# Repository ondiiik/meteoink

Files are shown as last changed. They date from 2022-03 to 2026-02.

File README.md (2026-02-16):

# Meteoink

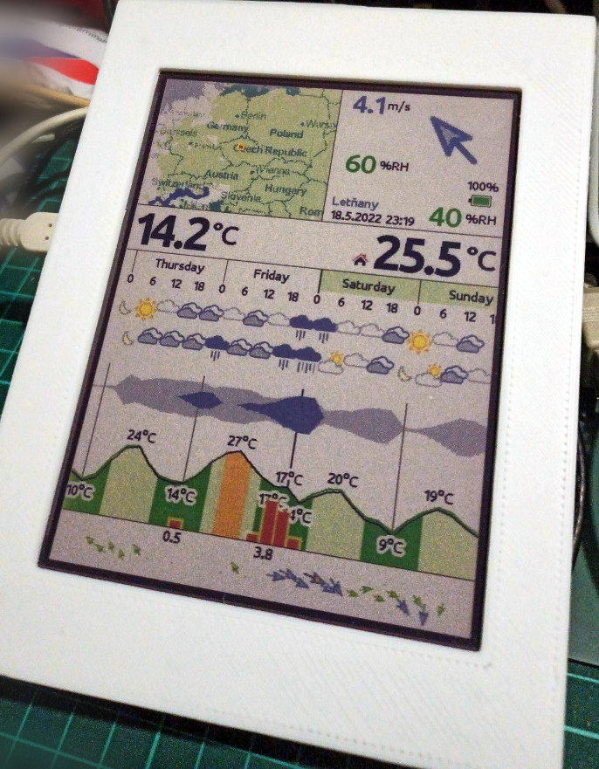
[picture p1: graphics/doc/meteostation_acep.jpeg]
EPD 5.65 ACEP inch meteostation


## What Meteoink is

Meteoink is home meteostation based on several variants of E-Ink displays such as
[5.65inch 7-color (F) E-Ink display](https://www.waveshare.com/wiki/5.65inch_e-Paper_Module_(F)_Manual) (variant `acep`) or
[4.2 inch dual color E-Ink display](https://www.waveshare.com/4.2inch-e-paper-module-c.htm) (variant `bwy`). In past
there has been support also for [T5-4.7 Inch E-paper](https://www.lilygo.cc/products/t5-4-7-inch-e-paper) (variant `epd47`)
but this has been dropped as there is no support for later variant of Micropython (unfortunately several last versions
does not support it due to Micropython version upgrade).

Platform running this meteostation is [Micropython 1.27.0](https://micropython.org/) running on
[TTGO-T8-ESP32](https://github.com/LilyGO/TTGO-T8-ESP32/tree/master) compatible board.

Meteostation is connected to your home WiFi and uses data from [OpenWeatherMap](https://openweathermap.org/).
It also may use [DHT22](https://github.com/semestrinis/Arduino/wiki/DHT22-temperature-humidity-sensor)
sensor for measuring indoor temperature and humidity, however advanced users may use some other MQTT sensor for
this purpose. Whole system is powered from one [Li-On battery](https://en.wikipedia.org/wiki/List_of_battery_sizes#Lithium-ion_batteries_(rechargeable)) charged through the USB on ESP board. Meteostation is usually operating in between 2 to 6 mounts
when refresh time is set to 15 minutes and there is good WiFi signal and internet connection with battery stronger then 3000 mAh.
This time may reduce when e.g. radar data or `acep` variant of display with longer refresh are used.

## Wiring

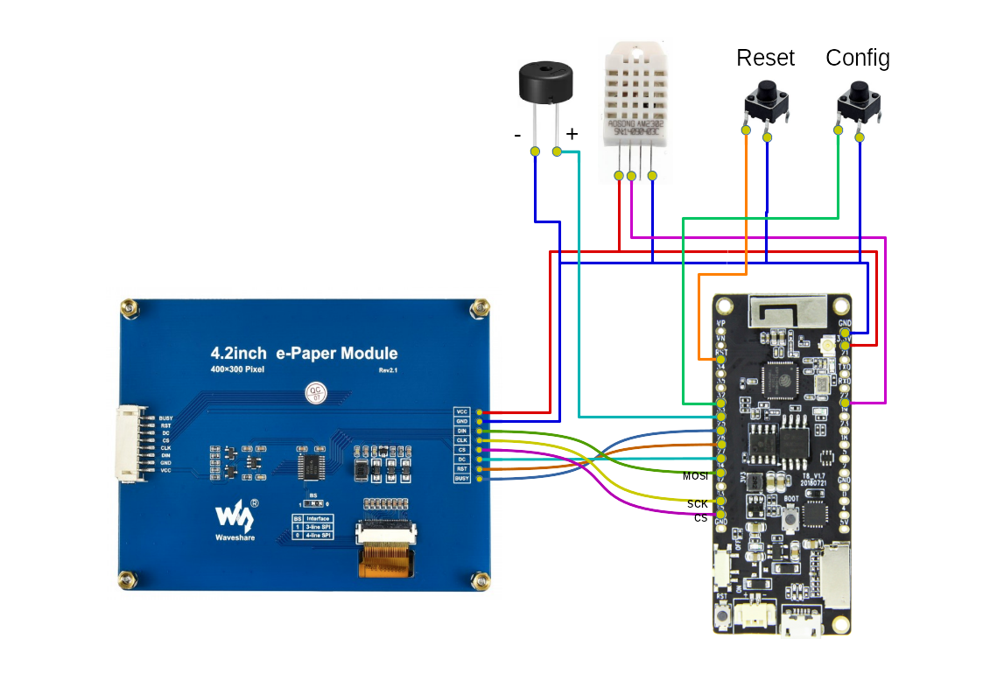
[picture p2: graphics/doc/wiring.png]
Meteostation wiring


Some pins can be moved to another position by changing config file [pins.py](https://github.com/ondiiik/meteoink/blob/master/esp32/micropython/acep/setup/pins.py).

However keep in mind that not all pins are available for any operation (some are not capable of ADC, some are not capable of SPI, ...).
Also battery is not displayed in wiring as it has its own connector so its connection is obvious.

## Box

Files for 3D printed parts are stored [here](https://github.com/ondiiik/meteoink/tree/master/box).

Both variants of box are partialy screwed and partially glued as well as electronics. To stitch processor board or battery
you can use acrylate 3M double side tape. DHT22 sensor is glued to chassis (grid for air access shall be on the side pointing
outside the box). When you glue it, apply glue very carefully as it shall not pass inside electronics
(especially in the case of buttons or DHT sensor). When all electronics is inside, then chassis shall be either glued to frame
(BWY variant) or screwed together (ACEP variant).

### BWY (EPD 4.2)

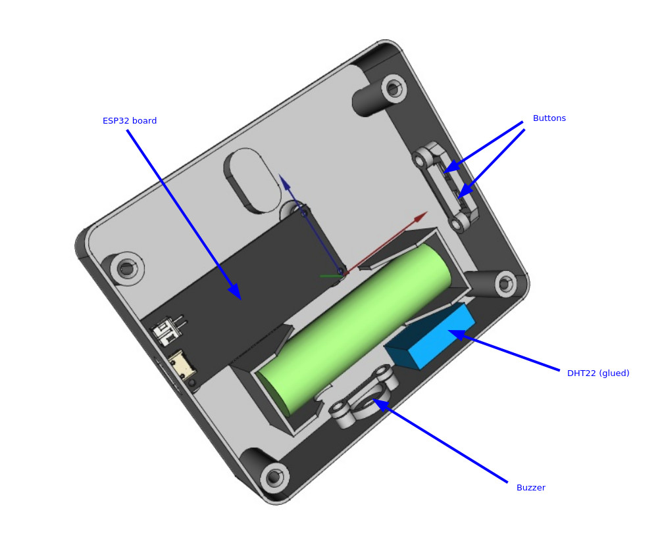
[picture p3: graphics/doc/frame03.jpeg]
3D printed frame

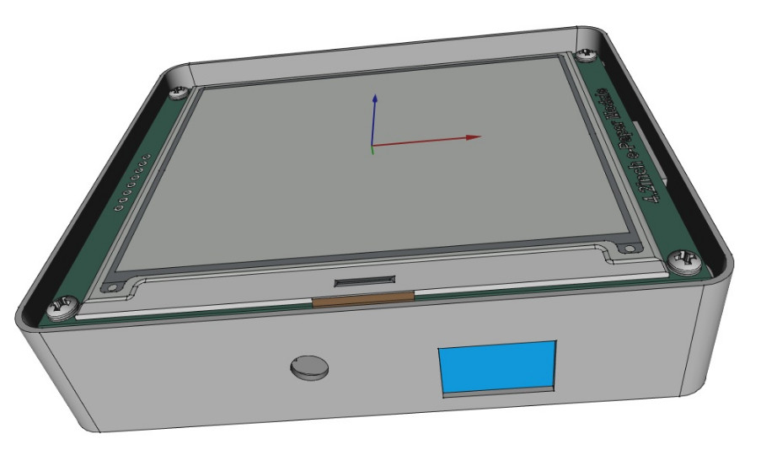
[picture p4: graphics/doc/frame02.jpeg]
3D printed frame

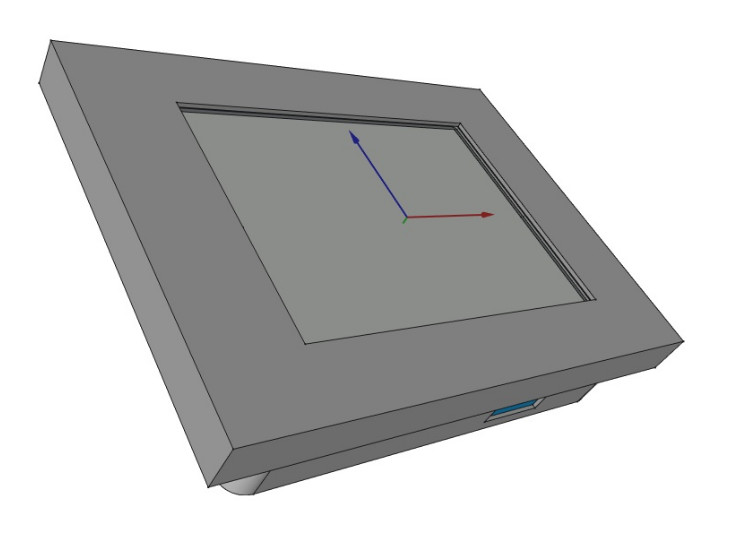
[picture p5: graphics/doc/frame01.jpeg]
3D printed frame


### ACEP (EPD 5.65)

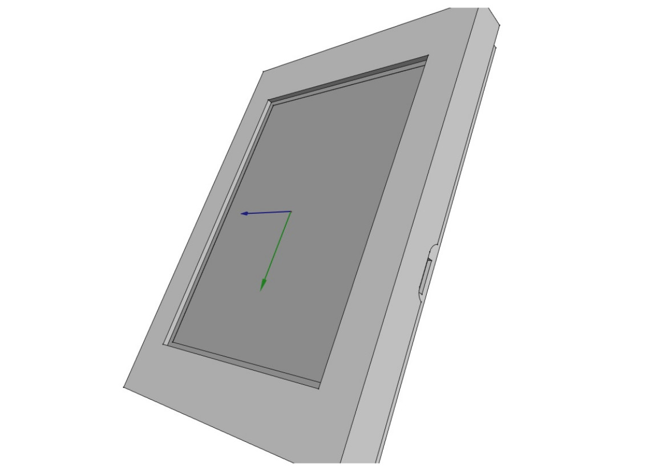
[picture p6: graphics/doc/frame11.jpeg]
3D printed frame

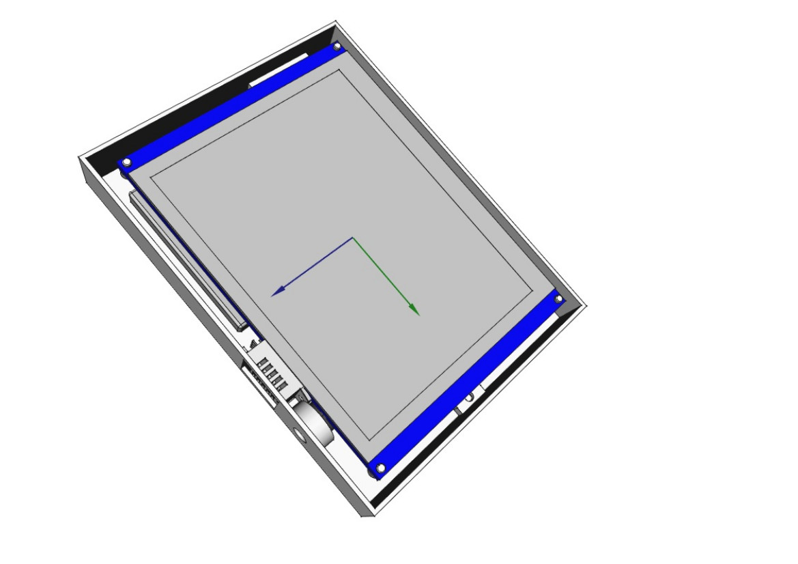
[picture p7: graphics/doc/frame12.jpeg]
3D printed frame

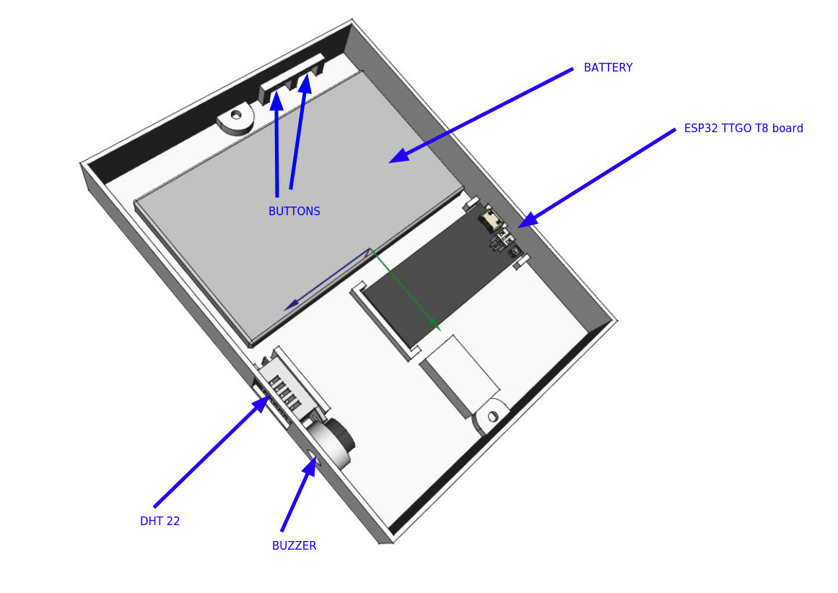
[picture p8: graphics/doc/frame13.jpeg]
3D printed frame

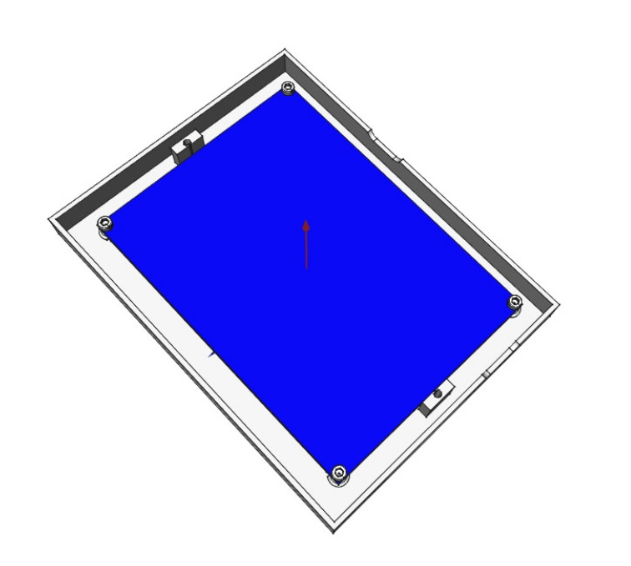
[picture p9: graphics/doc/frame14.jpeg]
3D printed frame


## Micropython

To make software running on ESP32, you have to install Micropython first on it. You shall use
[custom built of Micropython](https://github.com/ondiiik/meteoink/blob/master/esp32/micropython.bin) which contains
all necessary, including required python code. This also allow meteostation to startup way faster, what significantly
reduce battery consumption.

### Flashing of micropython

All necessary files can be found in [Release section](https://github.com/ondiiik/meteoink/releases). Currently
only `meteoink.bin` file is required.

To flash firmware to your ESP32 board you can use [flash\_firmware.sh](https://github.com/ondiiik/meteoink/blob/master/tools/flash_firmware.sh)
shell script. Just note that you will need to have installed [python interpreter](https://www.python.org/downloads/) first. 
You also need to have [esptool](https://pypi.org/project/esptool/) installed in your `python`. Once you have `python` installed
on your PC you can install `esptool` by following command:

```
pip install esptool
```

Then you can run [flash\_firmware.sh](https://github.com/ondiiik/meteoink/blob/master/tools/flash_firmware.sh) script to flash firmware into your
ESP32 board. You can use first argument to specify custom USB UART port where board is connected (otherwise `/dev/ttyUSB0`
is used by default) and second to locate firmware file (default is `meteoink.bin`) . Just note that this script will erase flash on ESP32 including
file system, so you can be sure that your previous data will be definitely lost (good idea to backup them before flashing). 

## Upload binary files

Each meteostation variant needs to upload also files with web content and binaries with graphics. This binaries are located in repository folder [esp32/micropython](https://github.com/ondiiik/meteoink/tree/master/esp32/micropython) for each variant of
display. There shall be also uploaded file `hw.json` into `cfg` describing in which mode and with which pins the meteostation
will work.

Once you have installed `python` on your PC you can use [ampy](https://techtutorialsx.com/2017/06/04/esp32-esp8266-micropython-uploading-files-to-the-file-system/) or
[Thonny IDE](https://randomnerdtutorials.com/getting-started-thonny-micropython-python-ide-esp32-esp8266/) to do this job for you.
Following files needs to be copied according to variant you use:

#### Files for variant ACEP

EPD 5.65 ACEP inch meteostation

  - all files from folder [esp32/micropython/acep](https://github.com/ondiiik/meteoink/tree/master/esp32/micropython/acep).
  - following `JSON` file into `cfg/hw.json` (this is also created automatically by default when this file is missing).

```
{
    "variant": "acep",
    "pins": {
        "sck": 13,
        "mosi": 14,
        "miso": 12,
        "cs": 15,
        "dc": 27,
        "rst": 26,
        "busy": 25,
        "dht": 22,
        "led": 21,
        "vbat": 35,
        "buzzer": 33
    },
    "buttons": {
        "hotspot": 32,
        "alert": -1,
        "sleep": -1
    }
}
```

#### Files for variant BWY

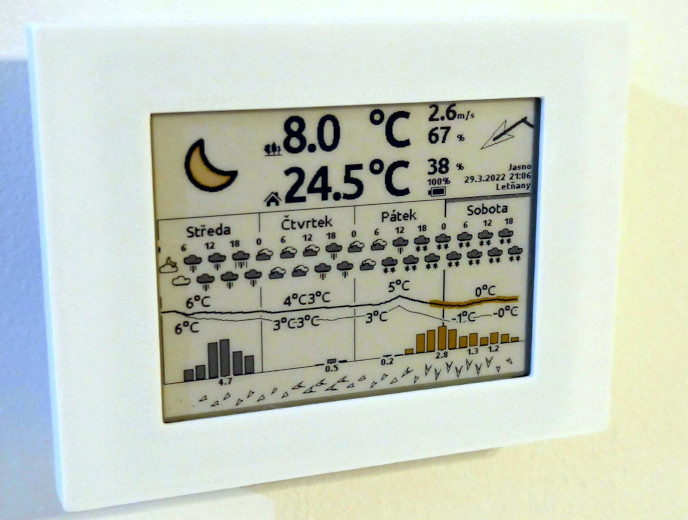
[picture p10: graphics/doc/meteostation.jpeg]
EPD 4.2 inch meteostation


  - all files from folder [esp32/micropython/bwy](https://github.com/ondiiik/meteoink/tree/master/esp32/micropython/bwy).
  - following `JSON` file into `cfg/hw.json`.

```
{
    "variant": "bwy",
    "pins": {
        "sck": 13,
        "mosi": 14,
        "miso": 12,
        "cs": 15,
        "dc": 27,
        "rst": 26,
        "busy": 25,
        "dht": 22,
        "led": 21,
        "vbat": 35,
        "buzzer": 33
    },
    "buttons": {
        "hotspot": 32,
        "alert": -1,
        "sleep": -1
    }
}
```

## Initial configuration

When all files are uploaded and meteostation restarted, it creates all missing `JSON` files in folder `cfg`. However
this initial data are missing some important data (API key, WiFi setup, location, ...). This causes that metostation
automatically switch to WiFi AP mode. You can use QR codes displayed on screen to setup your mobile phone WiFi to attach
to meteostation AP and open suitable WEB page.

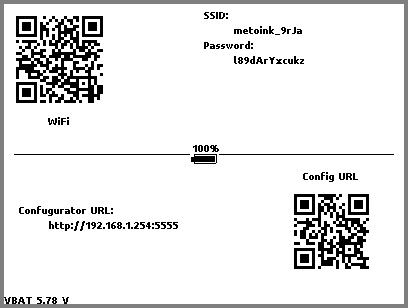
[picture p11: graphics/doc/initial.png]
Initial screen


Once you are connected to meteostation, you shall see webpage similar to this one:

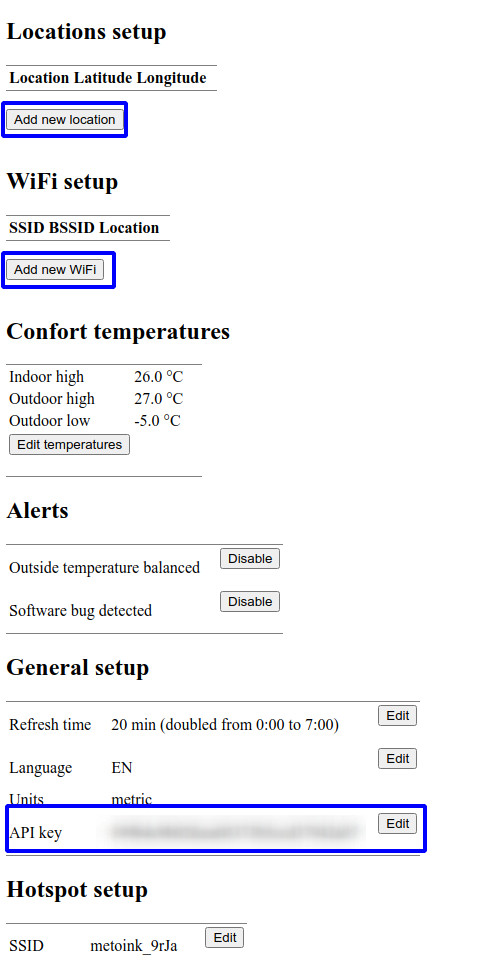
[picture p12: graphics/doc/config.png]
Config web page


To make station into operation you have to do following steps:

### Add your location

You shall add at least one location at the beginning. This location will be later used in WiFi configuration.
You can use more locations and bind them later to various WiFi, so when you are taking your weather station on holiday,
it choose location according to WiFi in your location.

### Add WiFi

Next step is to connect WiFi. When you attempt to connect WiFi, the list of available networks will be displayed.
Then you can choose one you want to use, assign suitable location and store it.

### Set OpenWeatherMap API key

The API key is long hash number which you shall
[get from OpenWeatherMap](https://home.openweathermap.org/users/sign_up). There are some personal API keys which are
for free however registration is required.

## Meteostation

Here we go ... once all above is passed, then simply press reset and wait till station is connected and forecast
displayed (it may take about one minute)

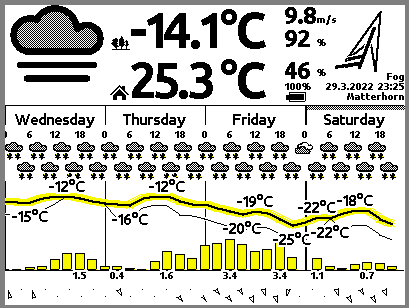
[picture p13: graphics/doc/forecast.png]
Forecast


## Reconfiguration

If you want to get into setup WEB page again, then you have restart meteostation when holding **config**
button, till beep (it may take a few seconds) and meteostation became to start to hotspot mode again.
Then QR codes appears on screen and configuration web server will be ready after next beep.

## Manual configuration

All items configured by WEB interface are at the end stored in [JSON](https://cs.wikipedia.org/wiki/JavaScript_Object_Notation) files
in `cfg` folder on device. If this files are missing, they are created automatically after first start of meteostation. This files
can be also edited manually (e.g. using [Thonny IDE](https://randomnerdtutorials.com/getting-started-thonny-micropython-python-ide-esp32-esp8266/)),
and they are then used after restart. However be careful when editing them, especially files `connection.json`
and `location.json`, where `connection.json` which uses index to `location.json` as reference and is easy to break binding between them.

Items in some of this files are described here:

### hw.json

```
{
    "variant": "acep",
    "pins": {
        "sck": 13,
        "mosi": 14,
        "miso": 12,
        "cs": 15,
        "dc": 27,
        "rst": 26,
        "busy": 25,
        "dht": 22,
        "led": 21,
        "vbat": 35,
        "buzzer": 33
    },
    "buttons": {
        "hotspot": 32,
        "alert": -1,
        "sleep": -1
    }
}
```

- `"variant"` - Variant of used board. Can be one of `"acep"` or `"bwy"`.
- `"pins"` - Configurations of pins used for communication with peripheries.
- `"buttons"` - Configurations of pins used for connecting of control buttons.

### api.json

```
{
    "apikey": "",
    "units": "metric",
    "language": "en",
    "variant": 4
}
```

- `"apikey"` - `apikey` obtained from [OpenWeatherMap](https://home.openweathermap.org/users/sign_up) used to download forecast.
- `"units"` - Which units shall be used (`"metric"` or `"imperial"`).
- `"language"` - Which language shall be used  (`"cz"` or `"en"`).
- `"variant"` - How much days shall be displayed in forecast (number in range from 2 to 5, where 2 uses more detailed variant of forecast).

### beep.json

```
{
    "temp_balanced": false,
    "error_beep": false
}
```

- `"temp_balanced"` - Boolean telling if outdoor and indoor temperatures are balanced (so you can open window and start cooling your house).
- `"error_beep"` - Boolean telling if station shell you notify by beeping when some software error occur (goot for long time testing).

### sys.json

```
{
    "exception_dump": 0,
    "log_level": "info",
    "led_enabled": false,
}
```

- `"exception_dump"` - Says how much bytes can be stored as exceptions dump into file system. Use 0 to disable this dumps.
- `"log_level"` - Verbosity of logging on UART terminal. Use one of `"debug"`, `"info"`, `"warning"`, `"error"` or `"critical"`.
- `"led_enabled"` - Tells if LED diode shall be used to report state of station (disable to safe a bit of battery juice).

### connection.json

This JSON file holds information about WiFi connections. Items here are created when new WiFi is connected, but they can be also edited manually for some special network related features such as MQTT sensors or similar.

```
{
    "connections": [
        {
            "location": 0,
            "ssid": "my great WiFi",
            "bssid": "12:34:56:78:9A:BC",
            "passwd": "123456789ABC",
            "mqtt": "ssl://mq_user@123456789:10.11.12.13:1883:topic=zigbee2mqtt/temperature_outside,out_temp=temperature,out_humi=humidity;topic=zigbee2mqtt/temperature_indoor,in_temp=temperature,in_humi=humidity"
        },
        .
        .
        .
    ]
}
```

- `"location"` - Index to location item stored in `locations.json` to know where WiFi is located (and download correct forecast).
- `"ssid"` - `SSID` (name) of the WiFi network.
- `"bssid"` - *Optional* - `BSSID` (base identifier) of the WiFi network. If present then WiFi is chosen based on it rather
  then SSID. This can be useful if there are more then one WiFi networks with the same `SSID`.
- `"passwd"` - Password used to connect the WiFi.

#### MQTT external sensor

In `connection.json` file there can be added `"mqtt"` tag to tell that this WiFi can be used to access `MQTT` broker
with temperature and humidity sensors. **Payload of this sensor shall be in [JSON](https://www.json.org) format and sensor
has to propagate its data as [retained](https://www.hivemq.com/blog/mqtt-essentials-part-8-retained-messages/)**.
With this tag e.g. [ZigBee2MQTT](https://www.zigbee2mqtt.io) outdoor and/or indoor sensors can be read (there can be even some
ZigBee indoor sensors used as outdoor when some shielding added). This even allow an absence of internal measuring sensor
such as `DTH22` and similar as indoor temperature can be obtained from some of ZigBee (or another `MQTT`) device.

Tag describing `MQTT` sensors to be read looks like following:

```
[ssl://][mqtt_user@mqtt_password:]broker_ip:broker_port:topic=some_topic,value1=json_name,...[;topic...]
```

There are several parts where separated by `:` delimiter.

- First part (`ssl://`) is optional and telling that `MQTT` broker communicates over `TLS`.
- Second part (`mqtt_user@mqtt_password`) is also optional and telling which user and password shall be used to login
  to broker when login required.
- Third and fourth part (`broker_ip:broker_port`) is address of `MQTT` broker.
- Then follows sets of topics and aliases (`topic=some_topic,value1=json_name,...`). This part can be repeated.
  Parts are separated by `;` delimiter.

Each MQTT topic part consists of several items separated by `,`. Each item has format `item=value`. Each topic part has to
contain at least one `topic` item telling which `MQTT` topic settle our sensor. Then each other item tells which `JSON`
value from `MQTT` payload will be interpreted as which variable. Following variables are supported:

- `out_temp` - Value represents outdoor temperature.
- `out_humi` - Value represents outdoor humidity.
- `in_temp` - Value represents indoor temperature. If there is internal sensor inside meteostation (e.g. `DHT22`)
  it's value vill be overwritten.
- `in_humi` - Value represents indoor humidity. If there is internal sensor inside meteostation (e.g. `DHT22`)
  it's value vill be overwritten.

##### Examples

Lets imagine we have `MQTT` broker on address `10.11.12.13` and port `1883` and have one
[ZigBee2MQTT](https://www.zigbee2mqtt.io) sensor outside presented by topic `zigbee2mqtt/temperature_outside`
getting following payload:

```
{
    "battery": 67,
    "humidity": 47.81,
    "linkquality": 145,
    "power_outage_count": 523,
    "pressure": 983.7,
    "temperature": 12.34,
    "voltage": 2912
}
```

In this case we can use its value as external value by following `"mqtt"` tag:

```
"10.11.12.13:1883:topic=zigbee2mqtt/temperature_outside,out_temp=temperature,out_humi=humidity"
```

When we need to specify user name (e.g. `mq_user`) and password (e.g. `123456789`) use following:

```
"mq_user@123456789:10.11.12.13:1883:topic=zigbee2mqtt/temperature_outside,out_temp=temperature,out_humi=humidity"
```

If we want to tell that our broker uses `TLS` on port `8883`, then we can use following:

```
"ssl://mq_user@123456789:10.11.12.13:8883:topic=zigbee2mqtt/temperature_outside,out_temp=temperature,out_humi=humidity"
```

In the case that we have also one more indoor sensor on topic `zigbee2mqtt/temperature_indoor`, we can add it to replace
built in meteostation sensor:

```
"ssl://mq_user@123456789:10.11.12.13:8883:topic=zigbee2mqtt/temperature_outside,out_temp=temperature,out_humi=humidity;topic=zigbee2mqtt/temperature_indoor,in_temp=temperature,in_humi=humidity"
```

## Others

### Translations

Currently supported languages are English and Czech, however any support for translation to another language is welcommed.
If someone wants to add the new language, it can be done in folder [lang](https://github.com/ondiiik/meteoink/tree/master/simulator/lang).
Translation is always a dictionary where the key is English sentence and the value is its translation.

If some additional characters needs to be added, this shall be done in file [font2png.py](https://github.com/ondiiik/meteoink/blob/master/graphics/font2png.py).
There is a line just like following containing supported characters:

`chars = 'aábcčdďeéěfghiíjklmnňoópqrřsštťuúůvwxyýzžAÁBCČDĎEÉĚFGHIÍJKLMNOÓPQRŘSŠTŤUÚŮVWXYÝZŽ0123456789'~!@#$%^&*()_+-[]{};\:"|,./<>?°' + "'"`

You can add your missing characters here. Please add only characters which are used by meteostation as this will became to be part of bitmaps loaded
into meteostation during startup. More characters means longer startup and shorter battery life per one charging cycle.

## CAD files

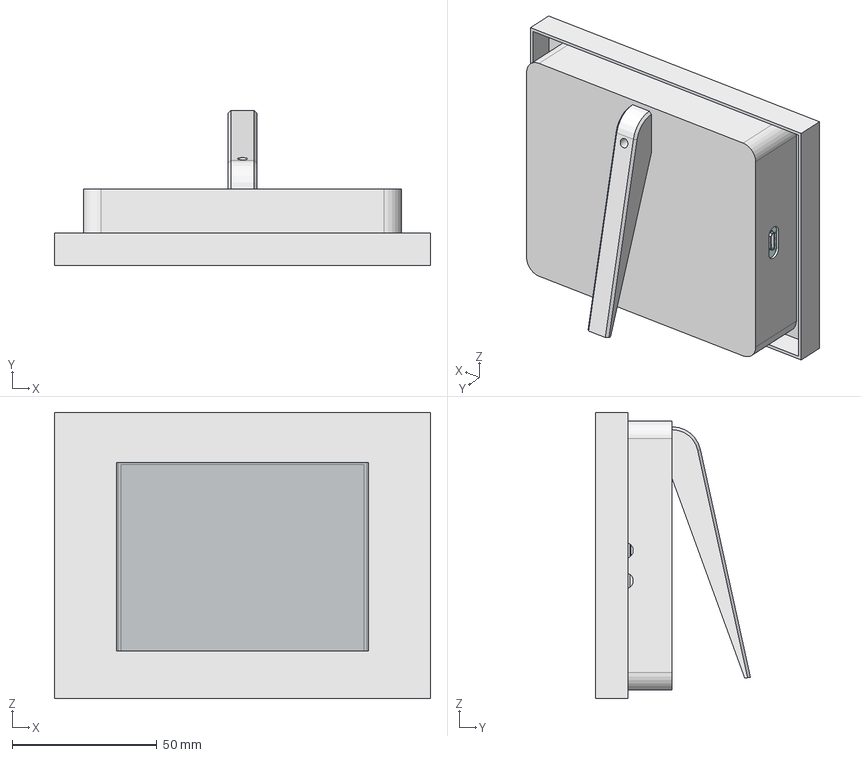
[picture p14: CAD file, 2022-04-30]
box/WallFrame_bwy42.FCStd
130.0 x 53.6 x 99.0 mm
W\X\FCrth 629105150521 Micro USB (Housing)
W\X\FCrth 629105150521 Micro USB (Inner Shield) x 3
W\X\FCrth 629105150521 Micro USB (Outer Shield)
W\X\FCrth 629105150521 Micro USB ( Contact 1,2,4,5) x 4
W\X\FCrth 629105150521 Micro USB ( Contact 3)
B2B-PH-K-S v1 x 3
Frame
Buttons holder
Buzzer holder
Leg
Waveshare 4.2 E-Ink - Display folded cable v1 x 2
PCB
90268A201 x 4
91772A030 x 4
Battery
DHT22

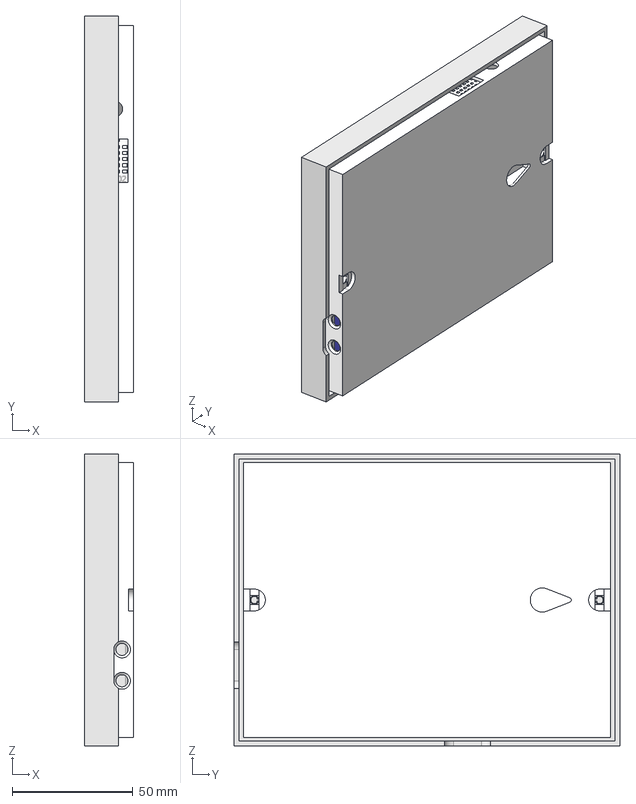
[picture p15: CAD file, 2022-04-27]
box/WallFrame_acep565.FCStd
20.2 x 160.0 x 121.0 mm
EInk
PCB x 2
M3x5-Screw x 4
Frame
Würth 629105150521 Micro USB (Housing)
Würth 629105150521 Micro USB (Inner Shield) x 3
Würth 629105150521 Micro USB (Outer Shield)
B2B-PH-K-S v1 x 3
3x4x2 tact button v1
DHT22 x 5
Buzzer

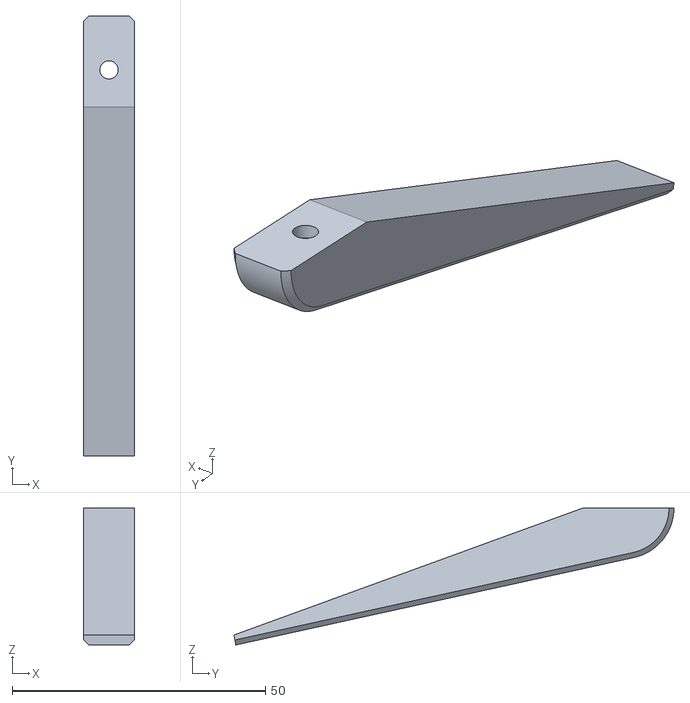
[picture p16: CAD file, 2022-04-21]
box/WallFrame_bwy42-MeteoLeg.stl
10.0 x 86.9 x 27.1

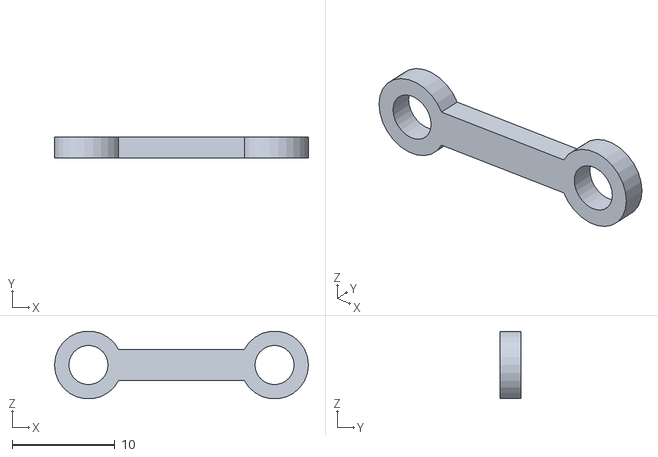
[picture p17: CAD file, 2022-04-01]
box/WallFrame_bwy42-MeteoBuzzer holder.stl
24.7 x 2.00 x 6.56

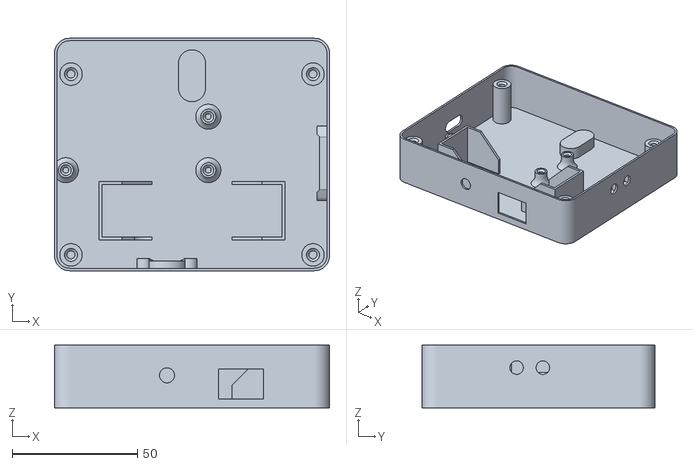
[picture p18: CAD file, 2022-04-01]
box/WallFrame_bwy42-MeteoBox.stl
110.0 x 93.0 x 25.0

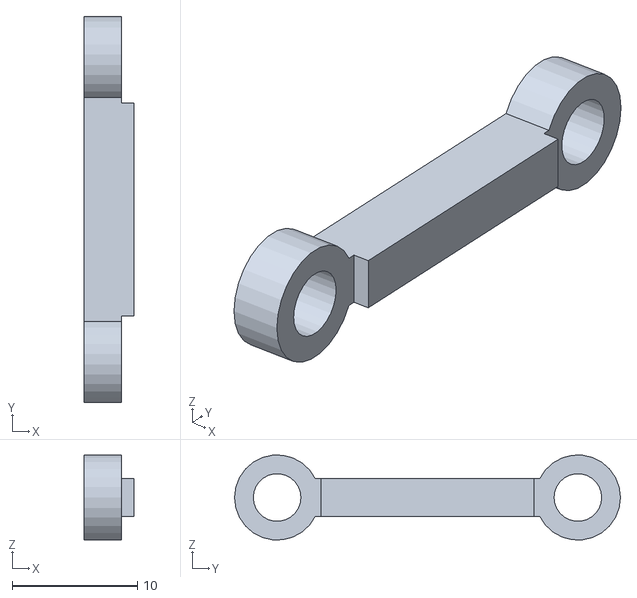
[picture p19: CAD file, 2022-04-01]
box/WallFrame_bwy42-MeteoButtons holder.stl
4.00 x 30.8 x 6.76

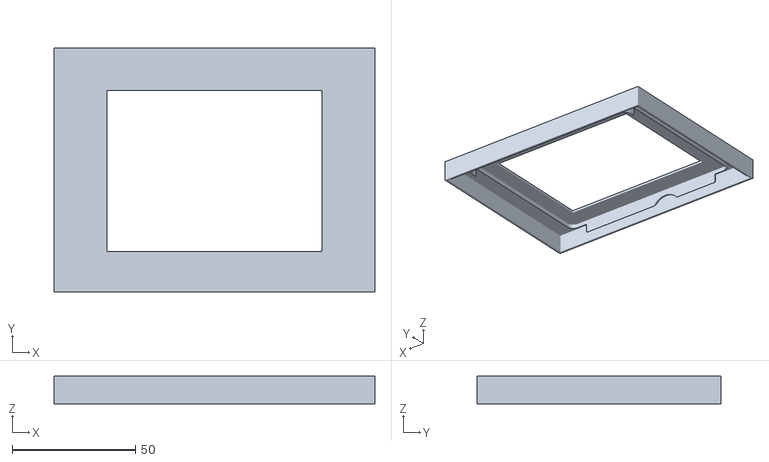
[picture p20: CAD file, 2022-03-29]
box/WallFrame_bwy42-MeteoFrame.stl
130.0 x 99.0 x 11.2

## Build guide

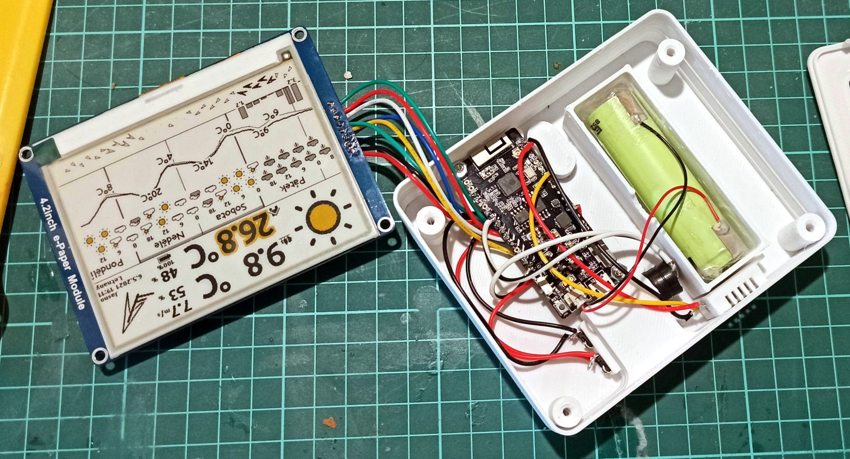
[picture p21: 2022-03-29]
graphics/doc/wiring.jpeg

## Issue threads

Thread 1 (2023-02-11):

setup.pins not available in pre-compiled esp32/micropython/acep

jjllddyy, 2023-02-11:
Unable to load from the precompiled /acep files (mpy 1.18):

`.. [main]                       Starting the application ...
!!! APPLICATION ERROR - REBOOTING !!!
Traceback (most recent call last):
  File "main.py", line 6, in <module>
  File "app.py", line 4, in <module>
  File "jumpers.py", line 5, in <module>
ImportError: no module named 'setup.pins'`

full console output:
`rst:0xc (SW_CPU_RESET),boot:0x13 (SPI_FAST_FLASH_BOOT)
configsip: 0, SPIWP:0xee
clk_drv:0x00,q_drv:0x00,d_drv:0x00,cs0_drv:0x00,hd_drv:0x00,wp_drv:0x00
mode:DIO, clock div:2
load:0x3fff0030,len:4540
ho 0 tail 12 room 4
load:0x40078000,len:12344
ho 0 tail 12 room 4
load:0x40080400,len:4124
entry 0x40080680
Reading database ...
Loading module ulogging
.. [main]                       Starting the application ...
!!! APPLICATION ERROR - REBOOTING !!!
Traceback (most recent call last):
  File "main.py", line 6, in <module>
  File "app.py", line 4, in <module>
  File "jumpers.py", line 5, in <module>
ImportError: no module named 'setup.pins'
ets Jun  8 2016 00:22:57`

ondiiik, 2023-03-01:
Unfortunately I'm unable to reproduce the issue. Module `setup.pins` is present in `acep` variant [here](https://github.com/ondiiik/meteoink/blob/master/esp32/micropython/acep/setup/pins.py) and works fine to me. Is this module present in your ESP32 file system?

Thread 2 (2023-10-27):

Make it compatible with waveshare ESP32 driver board

kalon33, 2023-10-27:
Dear ondiiik,

Would it be possible to make it compatible with the ESP32 driver board sold by Waveshare to drive the 5.65 ACEP EInk screen (https://www.waveshare.com/wiki/E-Paper_ESP32_Driver_Board)?

Thanks for your help and nice project.

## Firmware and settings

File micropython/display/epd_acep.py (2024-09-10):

# MicroPython Waveshare 5.65" 7 color e-paper display driver
# Based on https://github.com/mcauser/micropython-waveshare-epaper
#
# MIT License
# Copyright (c) 2017 Waveshare
# Copyright (c) 2018 Mike Causer
#
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
logger = getLogger(__name__)

from micropython import const
from time import sleep_ms
from struct import pack
from machine import SPI, Pin, deepsleep
from config import hw
from machine import deepsleep

ALPHA = const(7)
BLACK = const(0)
BLUE = const(3)
GREEN = const(2)
ORANGE = const(6)
RED = const(4)
WHITE = const(1)
YELLOW = const(5)

ACEP_PANEL_SETTING = const(0x00)
ACEP_POWER_SETTING = const(0x01)
ACEP_POWER_OFF = const(0x02)
ACEP_POWER_OFF_SEQUENCE = const(0x03)
ACEP_POWER_ON = const(0x04)
ACEP_BOOSTER_SOFT_START = const(0x06)
ACEP_DEEP_SLEEP = const(0x07)
ACEP_DTM = const(0x10)
ACEP_DISPLAY_REFRESH = const(0x12)
ACEP_PLL = const(0x30)
ACEP_TSE = const(0x40)
ACEP_CDI = const(0x50)
ACEP_TCON = const(0x60)
ACEP_RESOLUTION = const(0x61)
ACEP_PWS = const(0xE3)

_cleanup = b""


class EPD:
    @micropython.native
    def __init__(self):
        logger.info("Building display:")
        self.width = 600
        self.height = 448

        self._fb = bytearray((self.width * self.height + 1) // 2)

        p = hw["pins"]

        self._spi = SPI(1)
        self._spi.init(
            baudrate=2000000,
            polarity=0,
            phase=0,
            sck=Pin(p["sck"]),
            mosi=Pin(p["mosi"]),
            miso=Pin(p["miso"]),
        )
        logger.debug("\tSPI - [ OK ]")

        self._cs = Pin(p["cs"])
        self._dc = Pin(p["dc"])
        self._rst = Pin(p["rst"])
        self._busy = Pin(p["busy"])
        self._resolution = pack("!HH", self.width, self.height)

        self._cs.init(self._cs.OUT, value=1)
        self._dc.init(self._dc.OUT, value=0)
        self._rst.init(self._rst.OUT, value=0)
        self._busy.init(self._busy.IN)

        self._initialized = False

    @micropython.native
    def fb(self):
        return self._fb

    @micropython.native
    def display_frame(self):
        self._init()
        self._flush_frame(self._fb)
        self._sleep()

    @micropython.native
    def deghost(self):
        self._init()
        buf = bytearray((self.width * self.height + 1) // 2)
        for i in range(len(buf)):
            buf[i] = 0x77
        self._flush_frame(buf)

    @micropython.native
    def deepsleep(self, t):
        if t:
            deepsleep(t)
        else:
            deepsleep()

    @micropython.native
    def _cmd(self, command, data=None):
        self._dc(0)
        self._cs(0)
        self._spi.write(bytearray([command]))
        self._cs(1)
        if data is not None:
            self._data(data)

    @micropython.native
    def _data(self, data):
        self._dc(1)
        self._cs(0)
        self._spi.write(data)
        self._cs(1)

    @micropython.native
    def _flush_frame(self, buf):
        self._cmd(ACEP_RESOLUTION, self._resolution)
        self._cmd(ACEP_DTM, buf)
        self._cmd(ACEP_POWER_ON)
        self._wait4ready()
        self._cmd(ACEP_DISPLAY_REFRESH)
        self._wait4ready()
        self._cmd(ACEP_POWER_OFF)
        sleep_ms(500)

    @micropython.native
    def _reset(self):
        self._rst(True)
        sleep_ms(10)
        self._rst(False)
        sleep_ms(10)
        self._rst(True)
        sleep_ms(200)
        self._wait4ready()

    @micropython.native
    def _init(self):
        if self._initialized:
            return

        self._reset()
        self._wait4ready()

        sleep_ms(10)
        self._cmd(ACEP_PANEL_SETTING, b"\xEF\x08")
        self._cmd(ACEP_POWER_SETTING, b"\x37\x00\x23\x23")
        self._cmd(ACEP_POWER_OFF_SEQUENCE, b"\x00")
        self._cmd(ACEP_BOOSTER_SOFT_START, b"\xC7\xC7\x1D")
        self._cmd(ACEP_PLL, b"\x3C")
        self._cmd(ACEP_TSE, b"\x00")
        self._cmd(ACEP_CDI, b"\x37")
        self._cmd(ACEP_TCON, b"\x22")
        self._cmd(ACEP_RESOLUTION, self._resolution)
        self._cmd(ACEP_PWS, b"\xAA")
        sleep_ms(100)

    @micropython.native
    def _sleep(self):
        self._cmd(ACEP_POWER_OFF)
        self._wait4ready()
        self._cmd(ACEP_DEEP_SLEEP, b"\xA5")

    @micropython.native
    def _wait4ready(self):
        for i in range(2000):
            if self._busy.value():
                return
            sleep_ms(10)

        raise RuntimeError("EPD Timeout")

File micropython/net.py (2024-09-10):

from ulogging import getLogger, dump_exception

logger = getLogger(__name__)

from jumpers import jumpers
from network import WLAN, STA_IF, AP_IF
from config import connection, location, spot, api, beep
from utime import sleep
import urequests
from uerrno import ECONNRESET


CONN_RETRY_CNT = const(6)


class Wifi:
    def __init__(self, ssid, bssid):
        self.ssid = ssid
        self.bssid = bssid


class Connection:
    def __init__(self):
        self.is_hotspot = False
        self._ifc = None

        if jumpers.hotspot:
            logger.info("Setting hotspot by jumper")
            self.is_hotspot = True

        if not connection["connections"]:
            logger.warning("Forcing hotspot: Missing WiFi setup")
            self.is_hotspot = True

        if not location["locations"]:
            logger.warning("Forcing hotspot: Missing Location")
            self.is_hotspot = True

        if not api["apikey"]:
            logger.warning("Forcing hotspot: Missing API key")
            self.is_hotspot = True

    def connect(self):
        if self._ifc is not None:
            return

        try:
            # Scan networks in surrounding
            self._ifc = WLAN(STA_IF)

            if not self._ifc.active(True):
                raise RuntimeError("WiFi activation failed")

            sc = self._ifc.scan()
            self.nets = []

            for n in sc:
                self.nets.append(Wifi(n[0].decode(), n[1]))

            # self._ifc.active(False)

            # Start requested variant of connection
            if self.is_hotspot:
                self._hotspot()
            else:
                self._attach()
            logger.info("Connected to network")

            type(self)._connected = True
        except Exception as font:
            self.net = None
            dump_exception("Network connection error", font)

            if beep["error_beep"]:
                play((200, 500), (100, 500))

            raise

    def disconnect(self):
        logger.info(f"Disconnecting from WiFi ...")
        WLAN(STA_IF).active(False)
        WLAN(AP_IF).active(False)
        self._ifc = None

    @property
    def ifconfig(self):
        return self._ifc.ifconfig()

    def http_get_json(self, url):
        logger.info(f"HTTP GET: {url}")

        for _ in range(CONN_RETRY_CNT):
            try:
                return urequests.get(url).json()
            except OSError as e:
                if e.errno == ECONNRESET:
                    logger.warning("ECONNRESET -> retry")
                    continue
                logger.error(f"Connection error: {e}")
                ...
            except Exception as e:
                logger.error(f"Connection error: {e}")
                ...

        raise OSError("Page does not respond")

    def _attach(self):
        # Activate WiFi interface
        logger.info(f"Connecting to WiFi ...")
        self._ifc = WLAN(STA_IF)

        if not self._ifc.active(True):
            raise RuntimeError("WiFi activation failed")

        # Search first based on BSSID
        network = None

        for n in self.nets:
            bssid = bytes2bssid(n.bssid)
            for c in connection["connections"]:
                if bssid == c["bssid"]:
                    network = c
                    break
            else:
                continue
            break

        # Repeat the same for SSID if BSSID was not found
        if network is None:
            for n in self.nets:
                for c in connection["connections"]:
                    if n.ssid == c["ssid"]:
                        network = c
                        break
                else:
                    continue
                break

        # Checks if we have something and connect to WiFi
        if network is None:
            raise RuntimeError("No know WiFi found!")

        self.config = network

        self._ifc.connect(
            network["ssid"], network["passwd"], bssid=_bssid2bytes(network["bssid"])
        )

        for i in range(30):
            if self._ifc.isconnected():
                logger.info(f"Connected: {str(self.ifconfig)}")
                self.is_hotspot = False
                return

            logger.debug(f"Connecting ...")
            sleep(1)

        raise RuntimeError("Wifi connection refused")

    def _hotspot(self):
        # Create hotspot to be able to attach by FTP and configure meteostation
        self._ifc = WLAN(AP_IF)
        self._ifc.active(True)
        self._ifc.config(essid=spot["ssid"], password=spot["passwd"], authmode=3)

        while self._ifc.active() == False:
            sleep(1)

        self.is_hotspot = True
        logger.info(f"Running hotspot: {str(self.ifconfig)}")


def bytes2bssid(bssid):
    return ":".join("{:02X}".format(b) for b in bssid)


def _bssid2bytes(bssid):
    b1 = bssid.split(":")
    b2 = []
    for i in range(6):
        b2.append(int(b1[i], 16))
    return bytes(b2)

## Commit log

2020-09-12 Added battery level measurement
2020-09-13 Added support for buzzer
    [app.py, machine.py, main.py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]
2020-09-15 Test of 2 days detailed forecast
    [voltage.ods]
2020-09-16 Resolved JSON reader memory issue
    [app.py, forecast.py, main.py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]
2020-09-18 implements brown-out detection
    [voltage.ods]
2020-09-19 fixed battery measurement
2020-09-21 patch for esp32 socket getaddrinfo
2020-09-21 optimized text printing
2020-09-25 fixed web configuration interface
    [app.py, forecast.py, led.py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]
2020-10-16 WiFi goes automatically to hotspot when unable to attach
2020-10-20 Fixed low WiFi signal going to hotspot mode issue
    [app.py, main.py, net.py]
2020-12-02 Fixed snow forrecast and used bit larger font
    [app.py, forecast.py, main.py]
2020-12-28 Prepare to diverge to ESP32-SPIRAM variant
2021-06-01 Ported fixes from TTGO EINK 4.7 variant
    [app.py, forecast.py]
2022-04-01 Updated 3D frame
    [WallFrame-MeteoBox.stl, WallFrame-MeteoButtons holder.stl, WallFrame-MeteoBuzzer holder.stl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]
2022-04-18 Basic ACEP E-Ink without ui correction
    [app.py, epd_acep.py, forecast.py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]
2022-04-21 Fixed text alignment with rotated display
    [WallFrame-MeteoLeg.3mf, WallFrame-MeteoLeg.stl, WallFrame.FCStd]
2022-04-21 Fixed high temperature color for BWY variant
    [main.py]
2022-04-26 Fixed hotspot mode
    [WallFrame-MeteoLeg.3mf, WallFrame.FCStd, WallFrame_acep565-MeteoBox.stl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]
2022-04-27 Modified ACEP layout
    [WallFrame_acep565-MeteoFrame.stl, WallFrame_acep565.FCStd]
2022-04-30 Fixed graph layout
    [WallFrame_bwy42.FCStd]
2022-05-20 Added fix for wrong repaint item
    [base.py, main.py]
2022-05-23 Fixed MPY build script
    [main.py]
2022-07-03 Fixed temperature alert
2023-03-01 Fixed modification of connection
    [epd_acep.py, epd_bwy.py, main.py]
2023-08-25 Addds possibility to ignor BSSID
    On some meshing WiFi networks there can be various BSSID per one SSID. In this case we shall ignore BSSID selection as this may vary.
2023-09-03 Fixed low battery UI
    [app.py, machine.py, main.py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]
2023-09-13 Fixed weater forecast unreachable state
    [app.py, base.py, forecast.py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]
2023-09-25 Fixed inside temperature to show DHT sensor values
    [app.py, forecast.py, ulogging.py]
2023-11-17 Maps switched to openstreetmap.de
2024-04-16 Missing visibility fix & bumped to Micropython 1.22.2
    [forecast.py, main.py, png.py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]
2024-04-30 Added support for outside MQTT sensor
2024-05-02 Displayed two temperatures with additional outer sensor
2024-09-10 Major fixes in forecast download
    [app.py, forecast.py, net.py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]
2024-09-10 Fixed power-down meteostation mode
    [epd_acep.py, epd_bwy.py, epd_t5_gs.py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]
2024-09-10 Less deghosting to save battery
2026-02-16 Updated on Micropython 1.27.0
    [partitions-4MiBplus.csv]
2026-04-25 Modified support for remote display through one socket channel
2026-06-19 Fixed temperature balanced alerd to use MQTT sensor value if available
